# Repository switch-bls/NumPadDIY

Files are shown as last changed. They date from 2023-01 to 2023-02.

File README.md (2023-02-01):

# Projet NumPadDIY
Ce projet m'a conduit à réaliser un pavé numérique filaire pour mon bureau.
Il s'agit d'un pavé numérique complet avec la touche verr/num fonctionnelle et l'anti-ghosting.

Tenter la réalisation de ce projet vous demandera des compétences de base en soudure, impression 3D et programmation C. Bien sûr, assurez-vous également d'avoir une imprimante 3D et un poste à souder.

Fonctionnalité:
- Touche Pavé numérique
- Anti-ghosting
- port Micro USB

Matériel:
- 1 Arduino Pro Micro 
- 17 switch de clavier
- 17 diode
- Les touches correspondants au pavé numérique d'un clavier
- 6 vis M1
- Du câble
- Du filament 3D

## Étape 1 - impression 3D

La première chose à faire est d'imprimer la coque en 3D.
Elle ne comporte que 2 parties plutôt faciles à imprimé, j'ai utilisé du PLA pour ma part
Mon paramétrage d'imprimante devait être une d'épaisseur de 0.2 mm sans support.
L'imprimante depuis laquelle j'ai fait la coque est une anet a8.

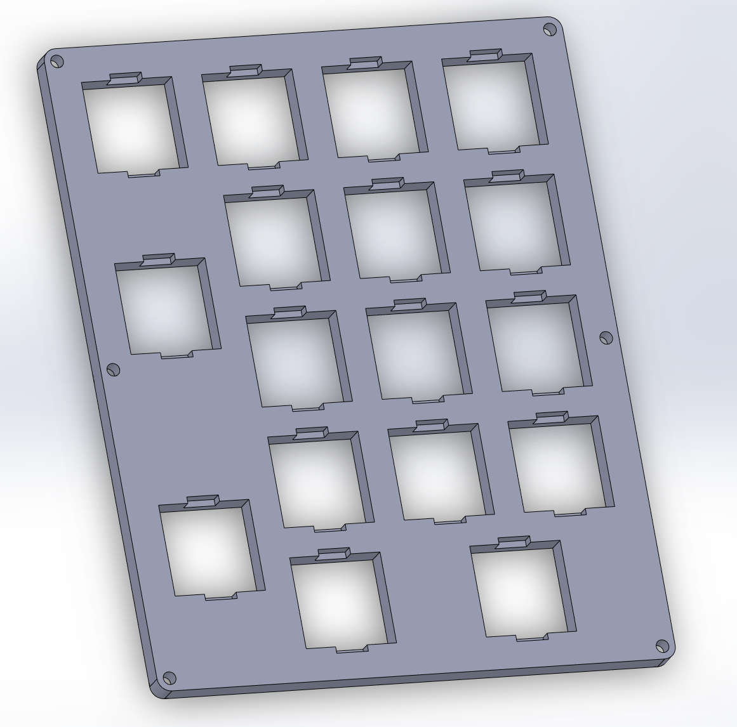
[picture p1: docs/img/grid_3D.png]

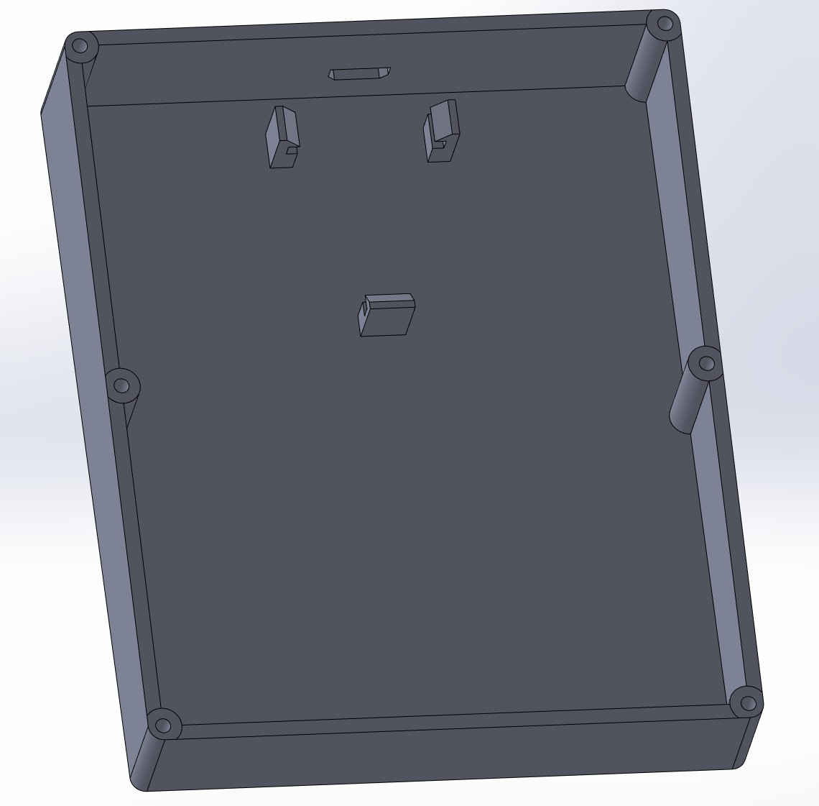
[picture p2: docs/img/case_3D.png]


Les fichier STL: https://github.com/switch-bls/NumPadDIY/tree/main/STL-3d-model

Les fichiers SolidWorks:  https://github.com/switch-bls/NumPadDIY/tree/main/SW-3d-model

## Étape 2 - Placer les switch

Placez simplement tout les switch dans le même sens sur la grille.

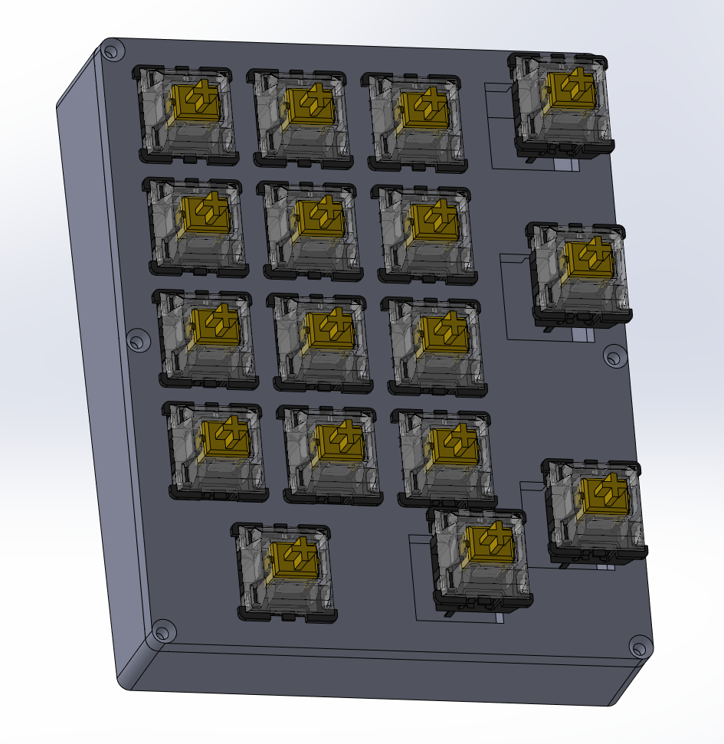
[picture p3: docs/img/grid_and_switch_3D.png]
grid_3D


Vous avez désormais une grille de bouton relier à rien. Maintenant on passe aux choses plus sérieuses.

## Étape 3 - Souder

C'est là que ça se complique, armez vous de patience pour l'étape la plus fastidieuse de ce projet (la soudure).

Tout d'abord il faut placer une diode sur chaque switche, toujours sur le même pin pour la gestion de l'anti-ghosting.

Nous allons vouloir relier les switch de notre clavier en une matrice. C'est-à-dire en ligne et en colonne, de sorte à en minimiser le nombre. Ce n'est pas grave si les lignes et les colonnes ne sont pas de la même taille.

Ce site explique en détaille l'intérêt de ce travaille:
- https://pcbheaven.com/wikipages/How_Key_Matrices_Works/

Voici mon résultat:

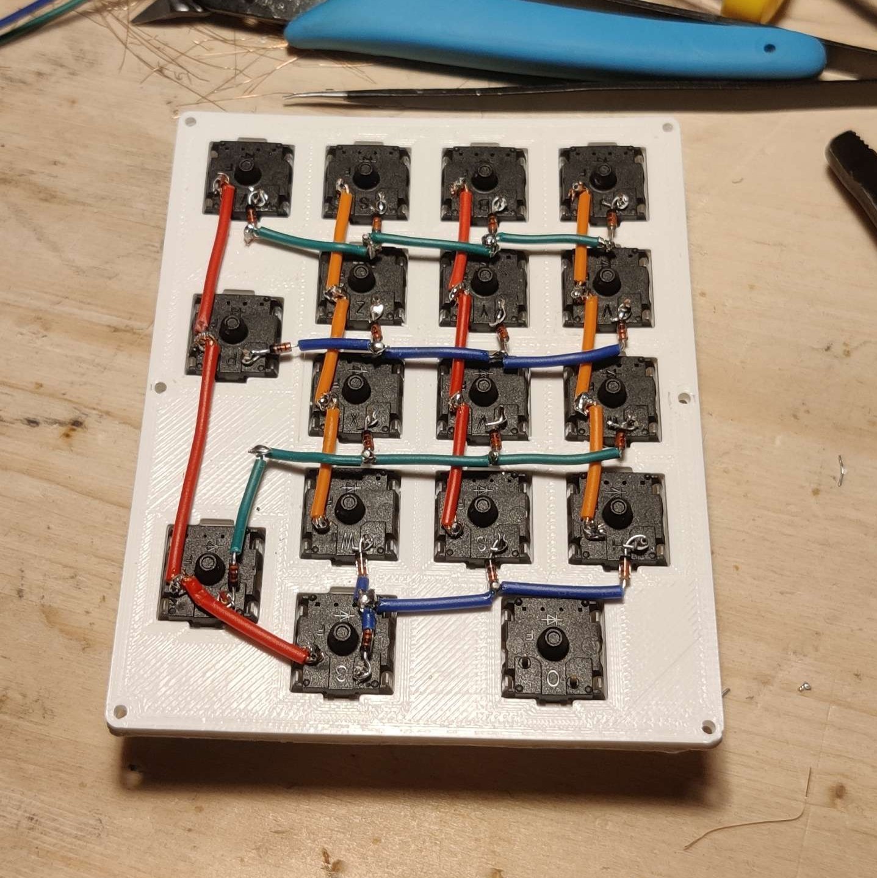
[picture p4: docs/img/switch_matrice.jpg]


Une matrice de 4*4+1.

Pour finir reliez chaque ligne et chaque colonne une fois à un pin digital de votre carte Arduino Pro Micro de sorte à laisser suffisamment de mou pour pouvoir tout positionner dans la boite.

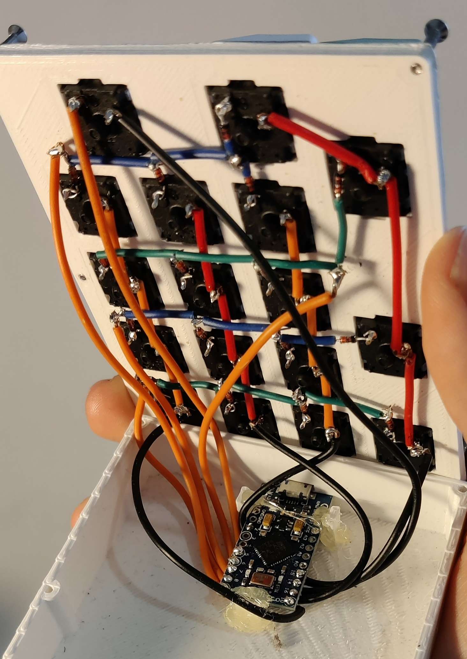
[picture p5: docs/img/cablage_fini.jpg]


Et voilà c'est fini pour la soudure!

## Étape 4 - Progrogrammer

Le code est le fichier ```code_keyboard.ino``` du projet.
Ce code n'est pas de moi, ***MAIS*** j'ai oublié la source dont il provient donc dsl pour l'auteur.

Si votre câblage est différent du mien, il va falloir adapter votre programme en conséquence.
Pas de panique, il s'agit de redéfinir quelque variable.

### Nombre de ligne et colonne
Placer le nombre de vos lignes et colonnes ici.
Ma matrice comportait 4x4+1 ce qui fait 5x5 pour ma part.

La variable *LAYERS* sert à définir différentes configuration de touches pour un même clavier mais elle n'est pas utile pour ce projet.

```C++
//Matrix Setup
const int LAYERS = 3;
const int ROWS = 5;
const int COLUMNS = 5;
```

### Définition des pins

Changez les numéros des pins pour ceux que vous avez connectés à votre micro controller. L'ordre n'est pas important.

```C++
//Input pins,
int ColPins[COLUMNS] = {8,9,7,6,5};
int RowPins[ROWS] = {14,2,16,15,10};
```

### Assigner les touches

Enfin il est temps d'assigner les touches de votre clavier à des actions dans le code (écrire des caractères). 

Tout d'abord il vous faudra initialiser un tableau de la taille de votre matrice.
Puis il faudra verifier ce que l'on appelle le scan-code de chaque touche en essayant de voir à quelle touche correspond quelle valeur.

Ici, le scan code est écrit en binaire, si vous le pouvez, faite le en hexadécimale se sera plus simple.

Pour connaître le scan-code des touche:
- https://forum.arduino.cc/t/numpad-keys/257542/4
- http://www.quadibloc.com/comp/scan.htm

```C++
const unsigned int Keymap[LAYERS][ROWS][COLUMNS] = 
{
  {//0 Raised layer
    {
      222,//  -
      235, // .
      223, // +
      224, // Enter
      NO_ACTION //  
    },
    {
      221, // *
      227, // 3
      233, // 9
      230, // 6
      NO_ACTION  // 
    },
    {
      220, // //
      226, // 2
      232, // 8
      229, // 5
      NO_ACTION  //
    },
    {
      NO_ACTION, //
      NO_ACTION, // 
      NO_ACTION, //
      NO_ACTION, // 
      234, // 0
    },
    {
      219,  // META
      225,  // 1
      231, // 7
      228,  // 4
      NO_ACTION,  
    }
   }
 };
```

## Étape 4 - Assemblage finale

Une fois cette opération achevéé, il ne reste qu'à coller la carte à l'emplacement prévu. J'ai utilisé du pistolet à colle pour ça.

Vissez le tout avec des vis M1 et placez vos keyCap sur les switches correspondant si ce n'est pas déjà fait et voilà!

Votre Pavé Numérique est opérationnel.

## Sources utiles

- https://pcbheaven.com/wikipages/How_Key_Matrices_Works/
- http://www.philipstorr.id.au/pcbook/book3/scancode.htm
- http://www.quadibloc.com/comp/scan.htm
- https://forum.arduino.cc/t/numpad-keys/257542/4

<style>
img{max-width:500px;}
img{min-width:300px;}
img{width:49%;}
</style>

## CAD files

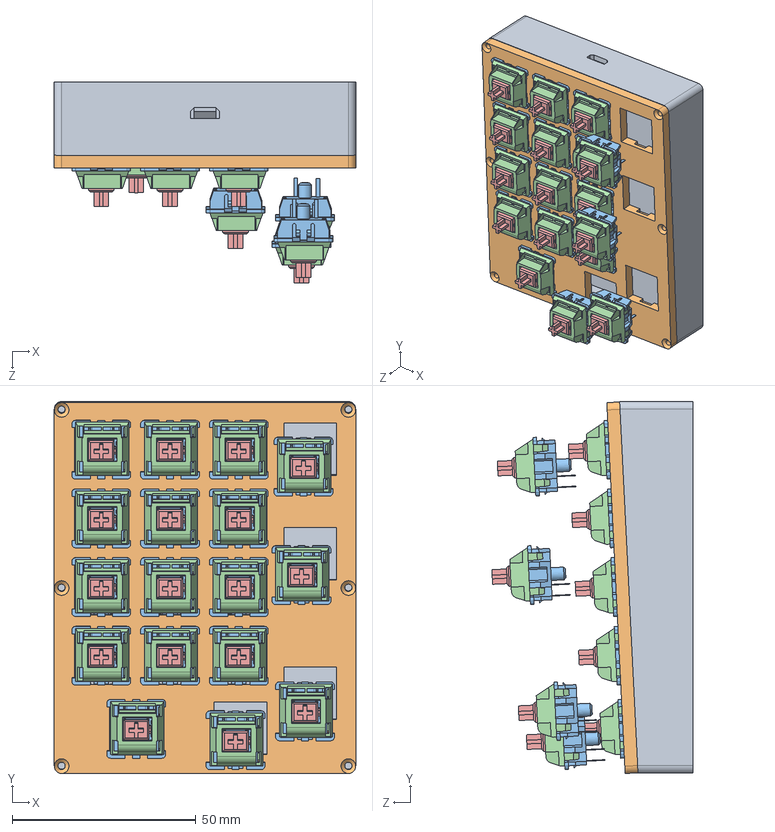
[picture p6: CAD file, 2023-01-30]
SW-3d-model/Assemblage2.SLDASM
82.0 x 101.2 x 54.7 mm
Case1.0
SwitchHolder3.2
CherrySwitchBottom1 x 17
CherrySwitchTop1 x 17
Piston1 x 17

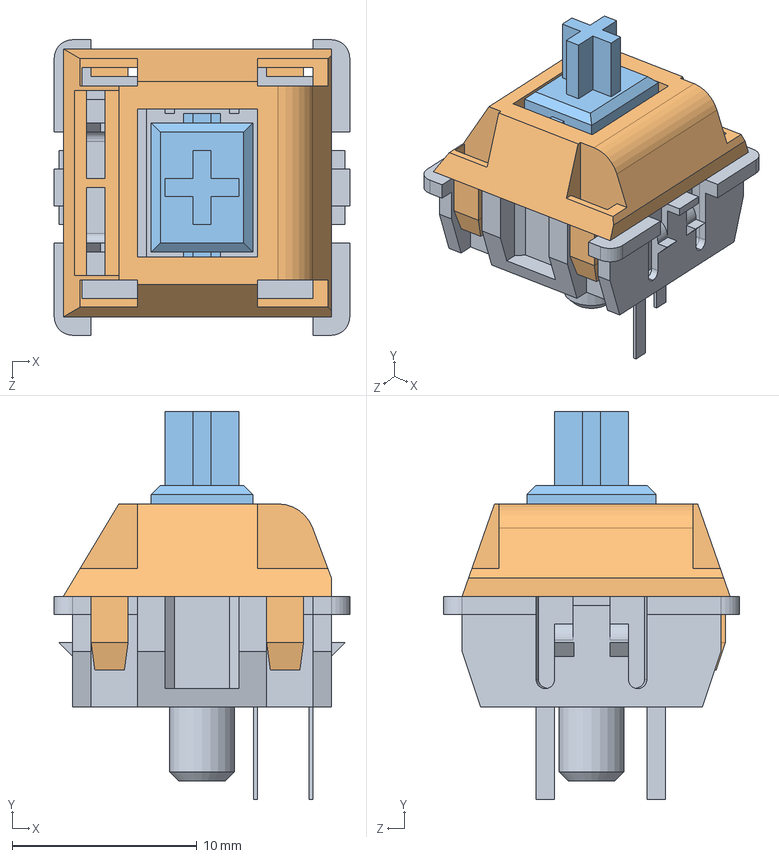
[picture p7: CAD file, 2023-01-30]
SW-3d-model/Assemblage1.SLDASM
16.0 x 21.0 x 16.0 mm
CherrySwitchBottom1
CherrySwitchTop1
Piston1

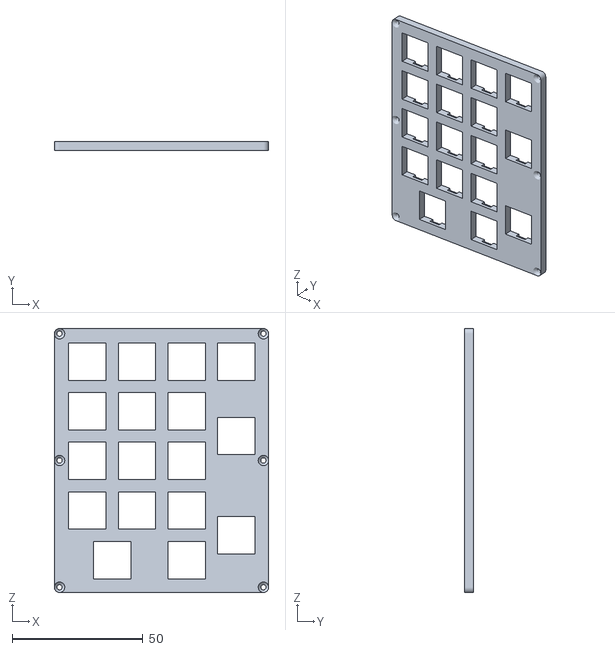
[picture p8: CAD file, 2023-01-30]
STL-3d-model/SwitchHolder3.2.STL
82.0 x 3.50 x 101.0

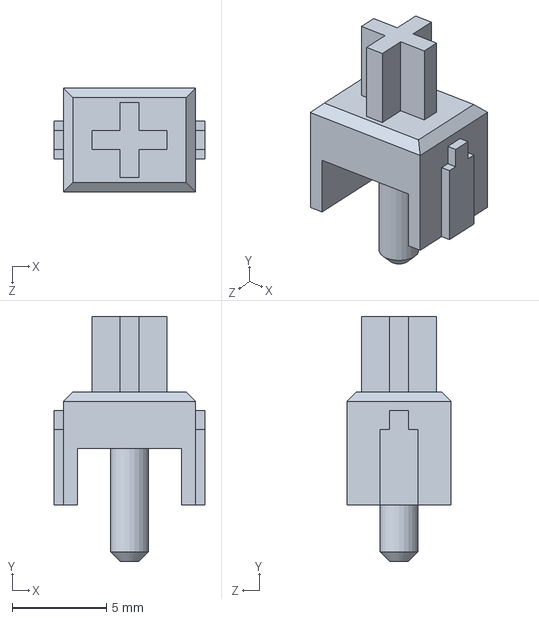
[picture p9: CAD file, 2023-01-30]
SW-3d-model/Piston1.SLDPRT
8.00 x 13.0 x 5.50 mm

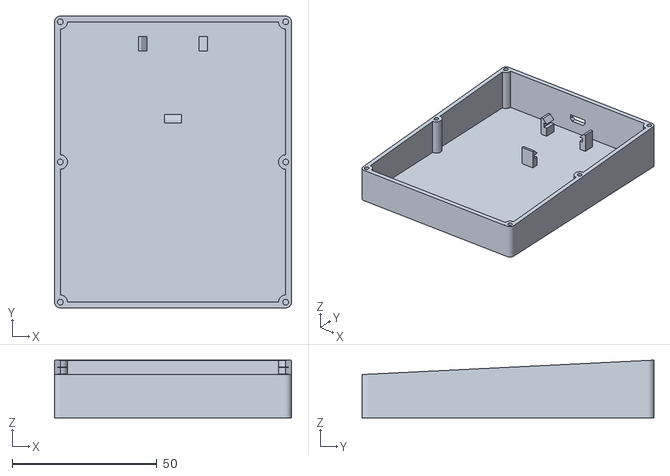
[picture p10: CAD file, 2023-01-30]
STL-3d-model/Case1.0.STL
82.0 x 101.0 x 20.0

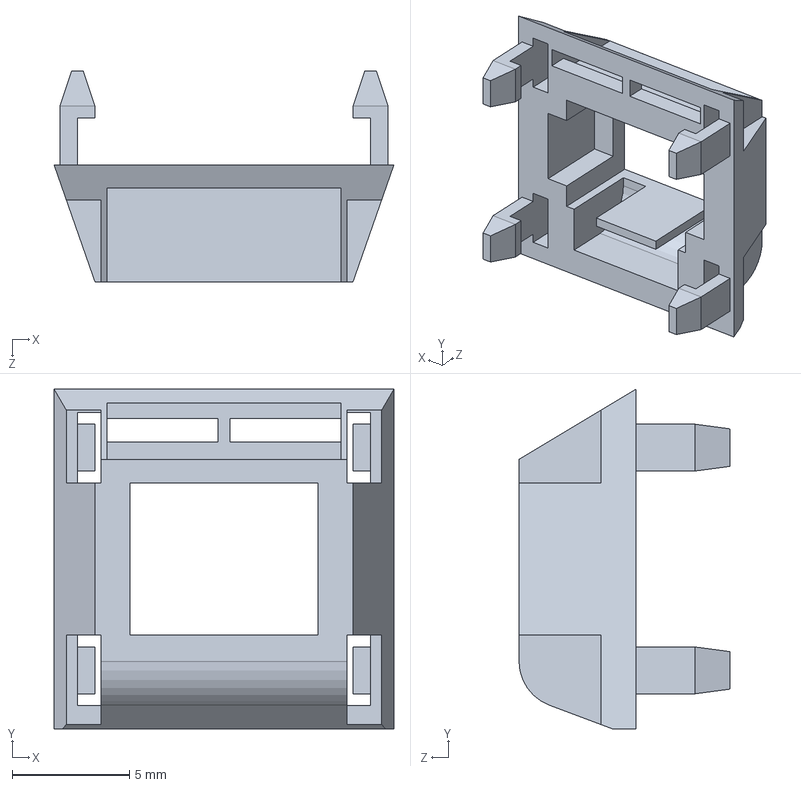
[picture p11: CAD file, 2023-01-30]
SW-3d-model/CherrySwitchTop1.SLDPRT
14.5 x 14.5 x 9.00 mm

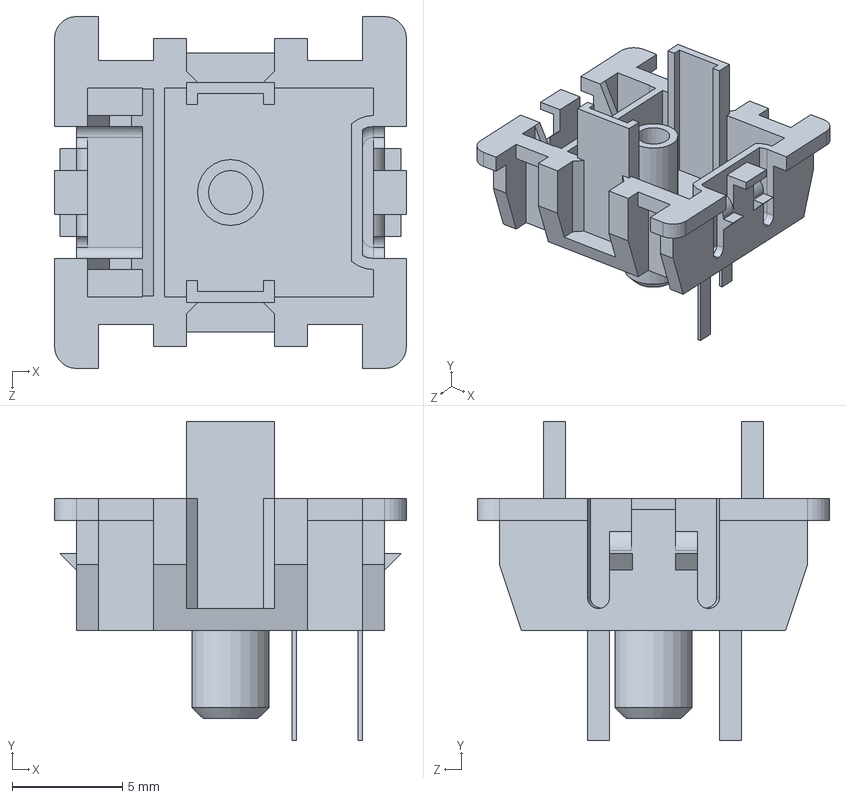
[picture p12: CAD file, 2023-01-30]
SW-3d-model/CherrySwitchBottom1.SLDPRT
16.0 x 14.5 x 16.0 mm

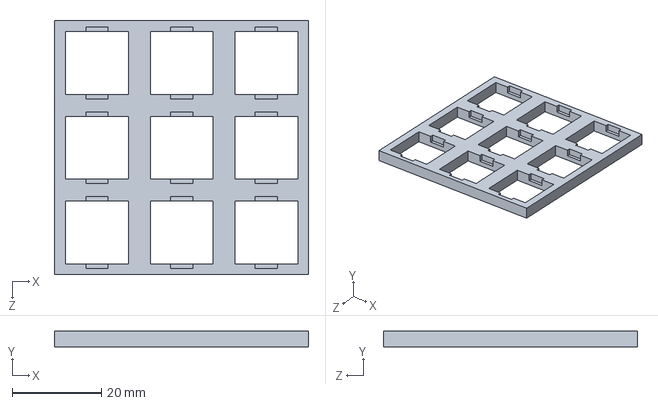
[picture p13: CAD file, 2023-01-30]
SW-3d-model/SwitchHolder2.1.SLDPRT
57.0 x 3.50 x 57.0 mm

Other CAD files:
SW-3d-model/Case1.0.SLDPRT
SW-3d-model/SwitchHolder3.2.SLDPRT

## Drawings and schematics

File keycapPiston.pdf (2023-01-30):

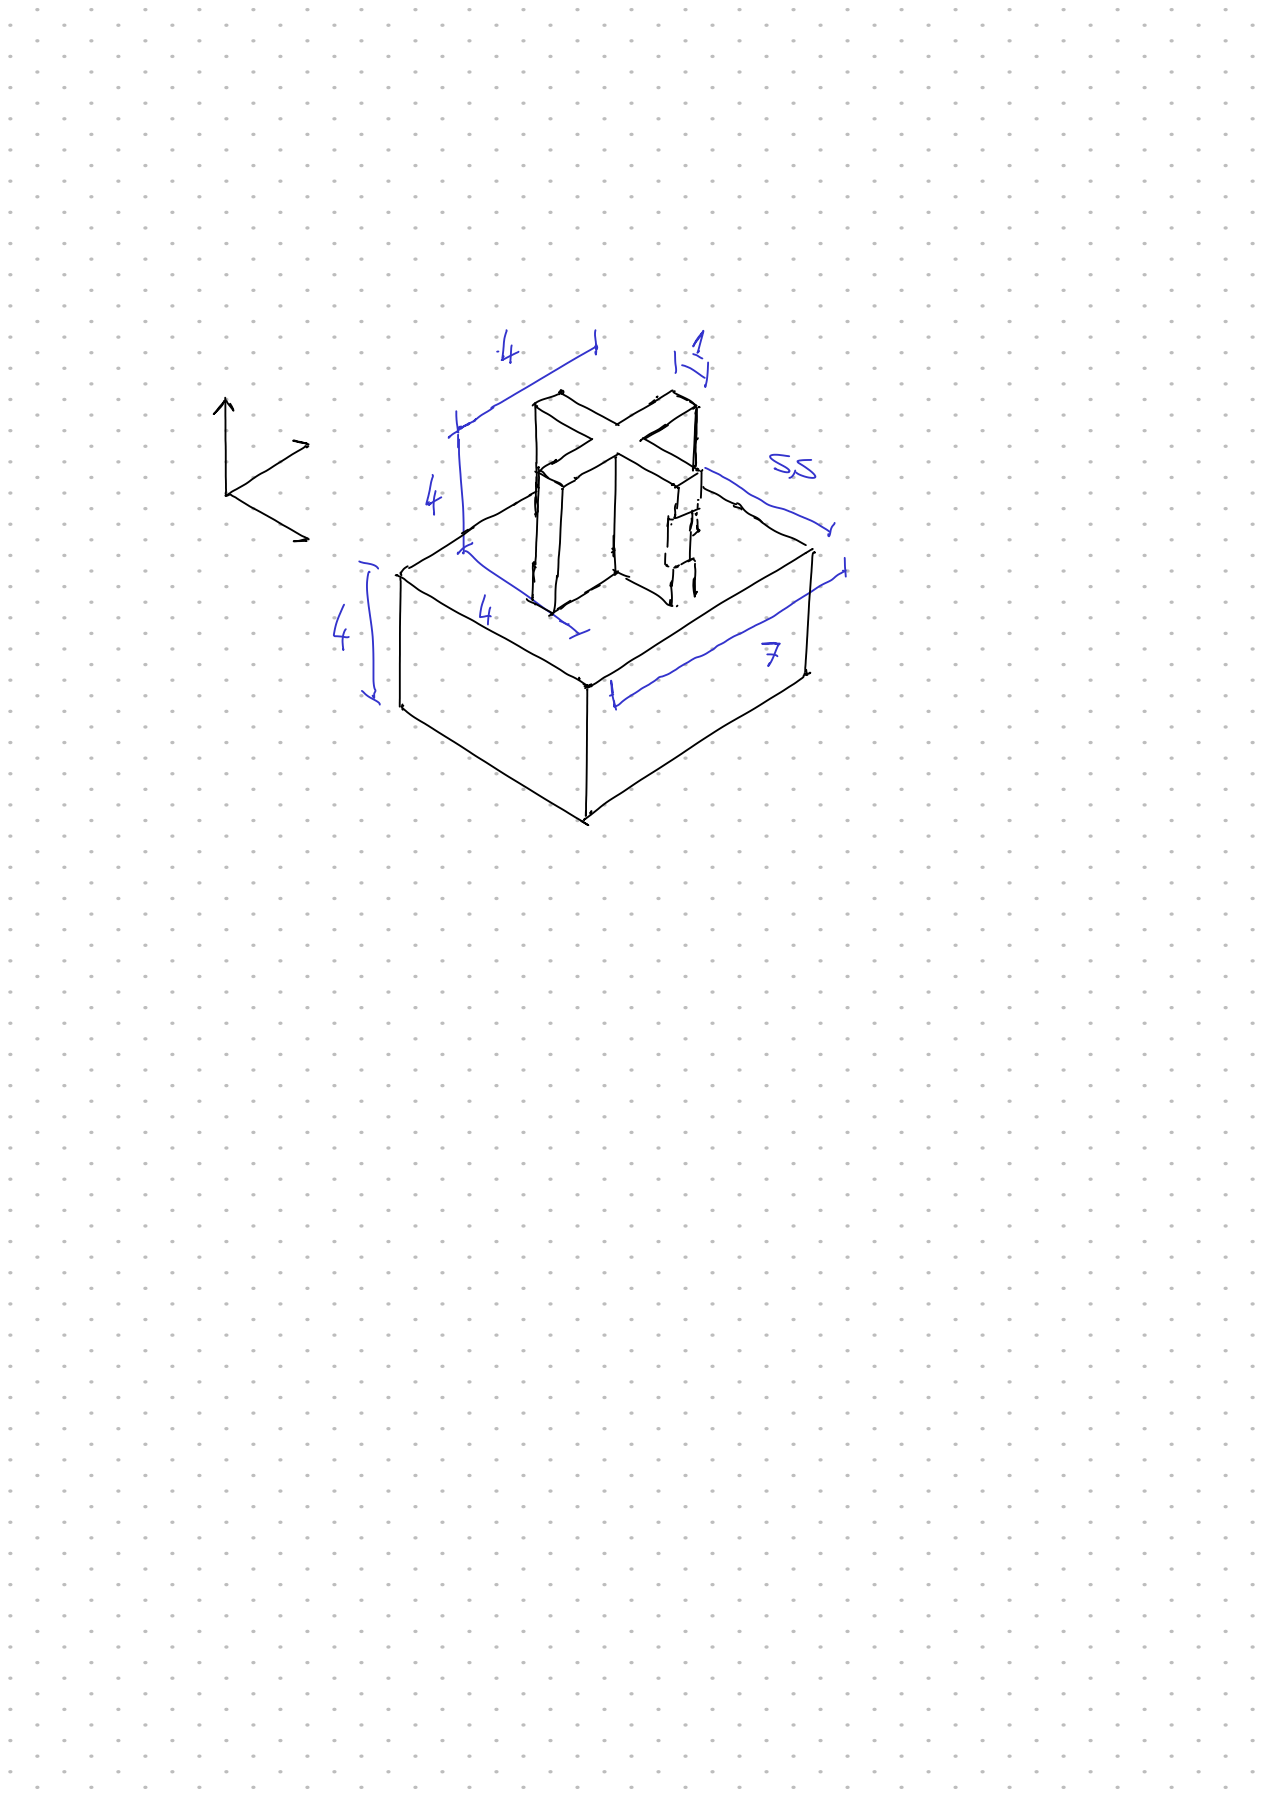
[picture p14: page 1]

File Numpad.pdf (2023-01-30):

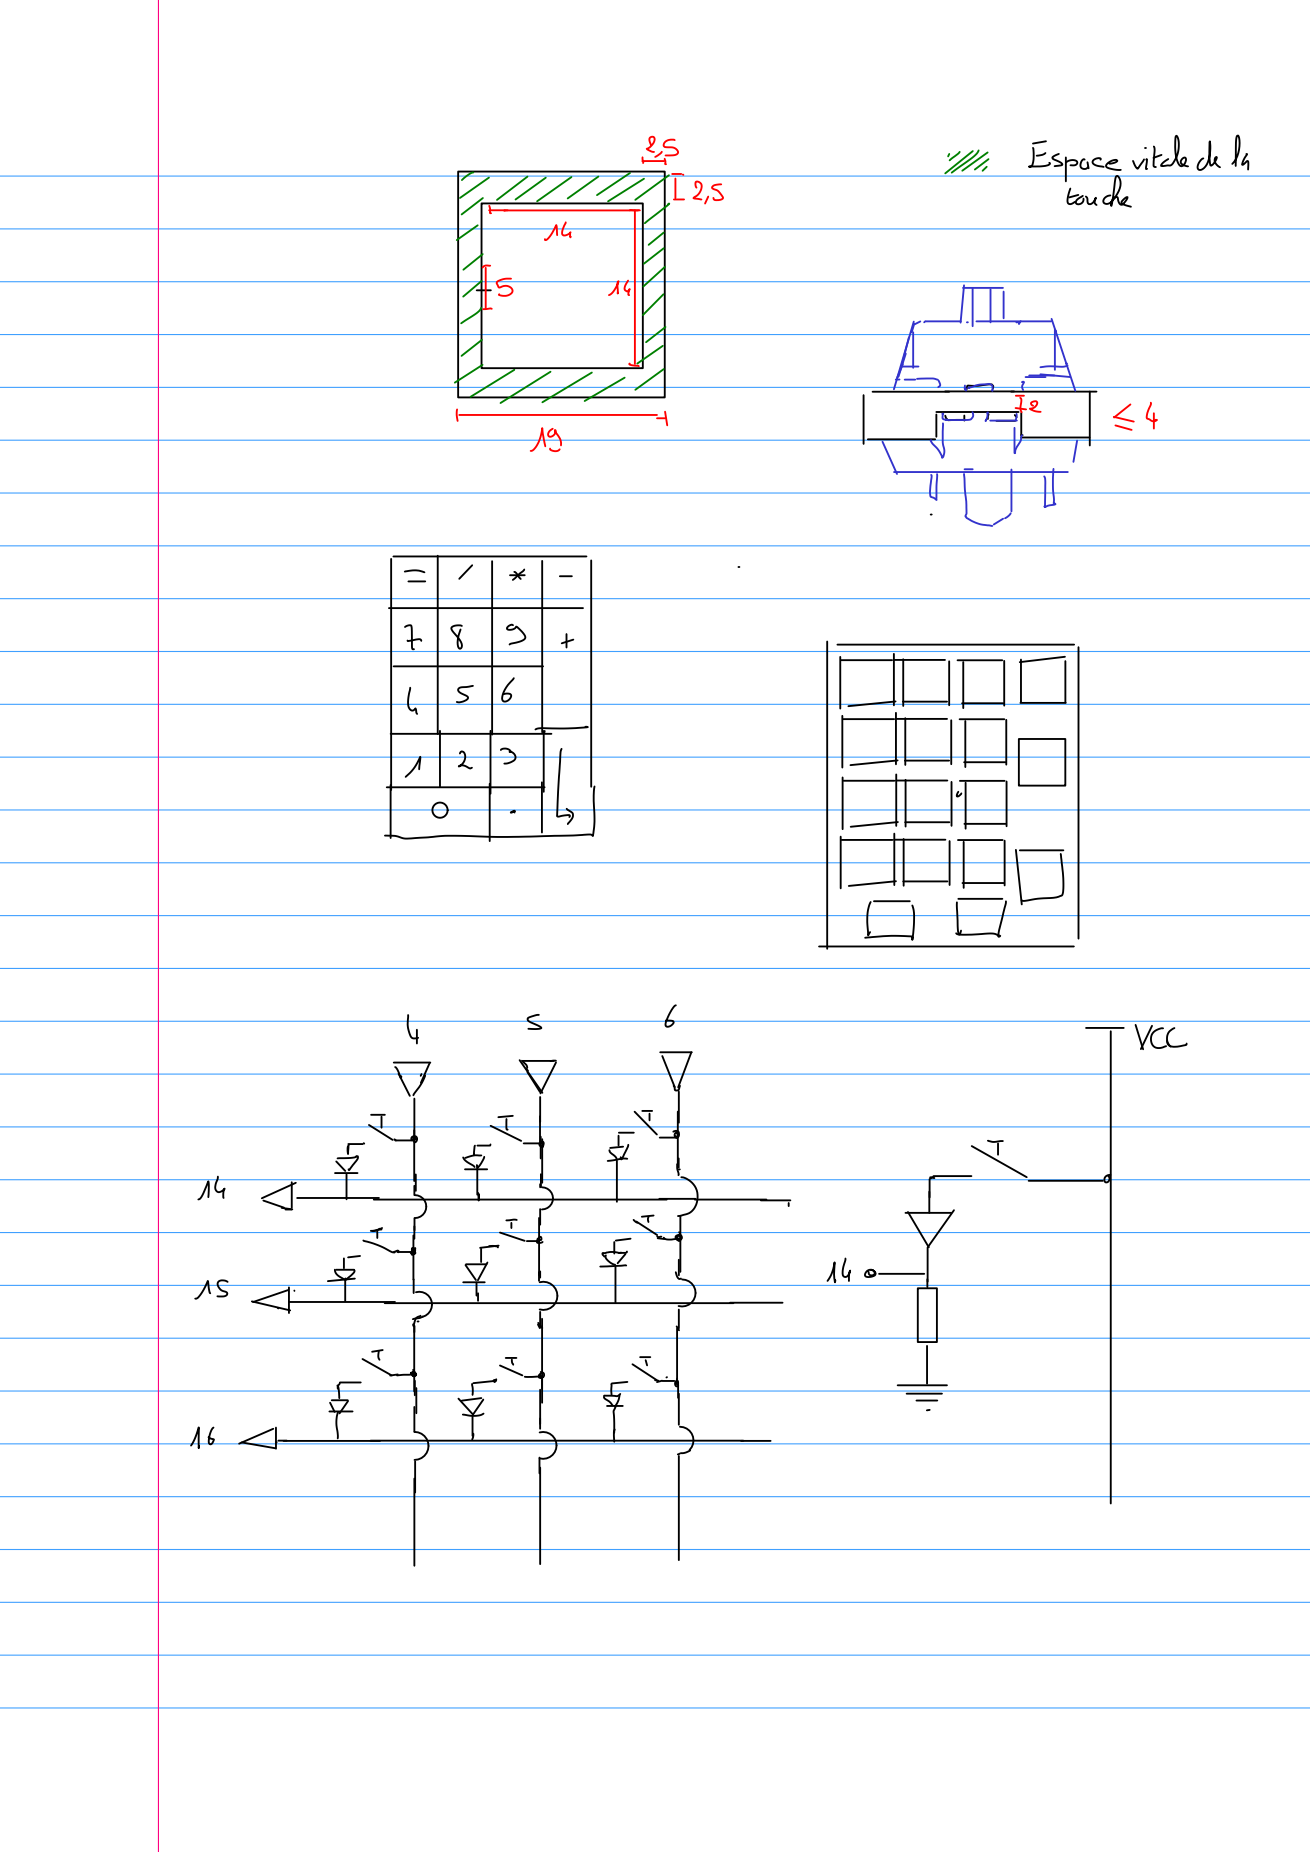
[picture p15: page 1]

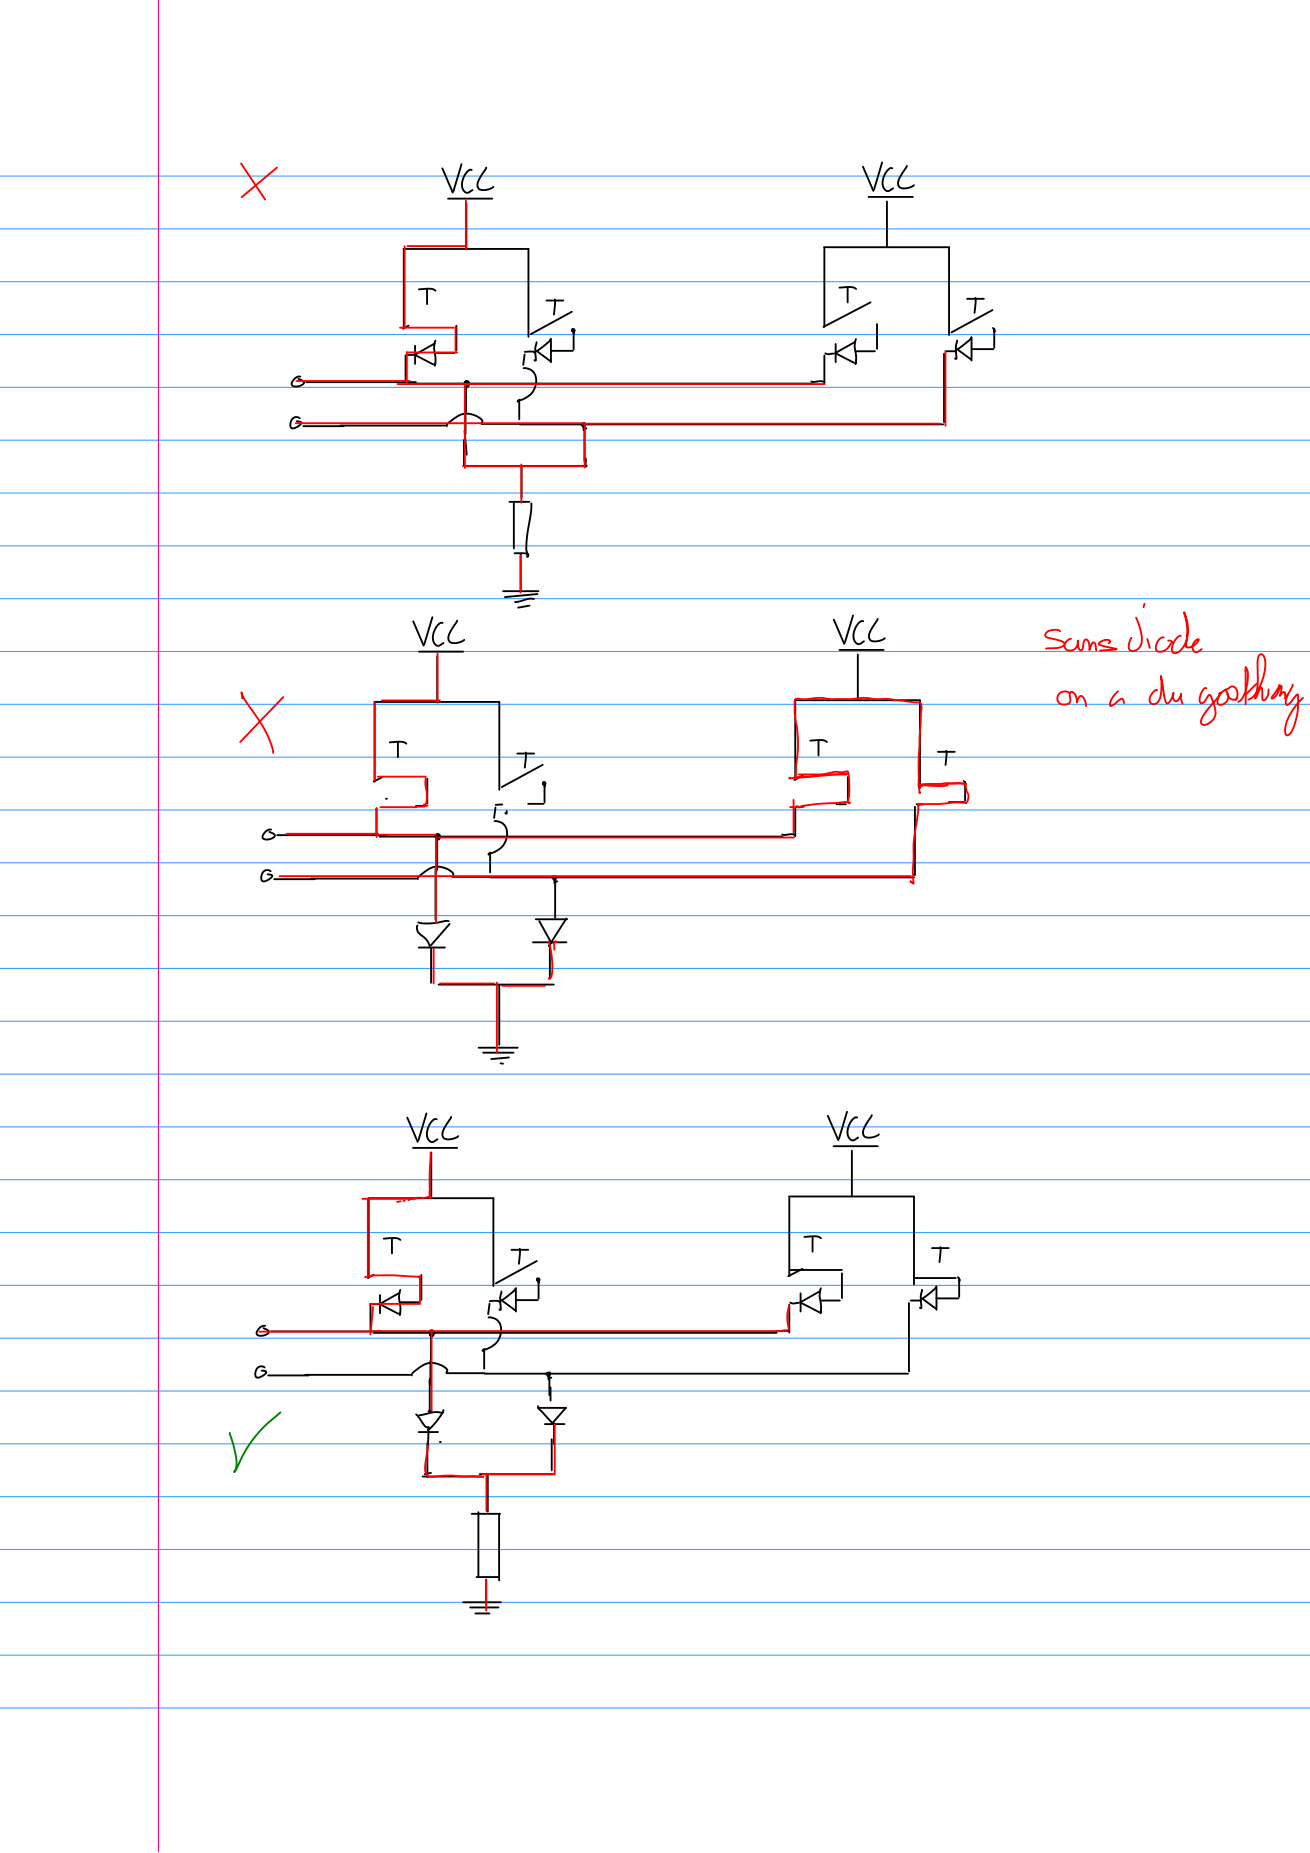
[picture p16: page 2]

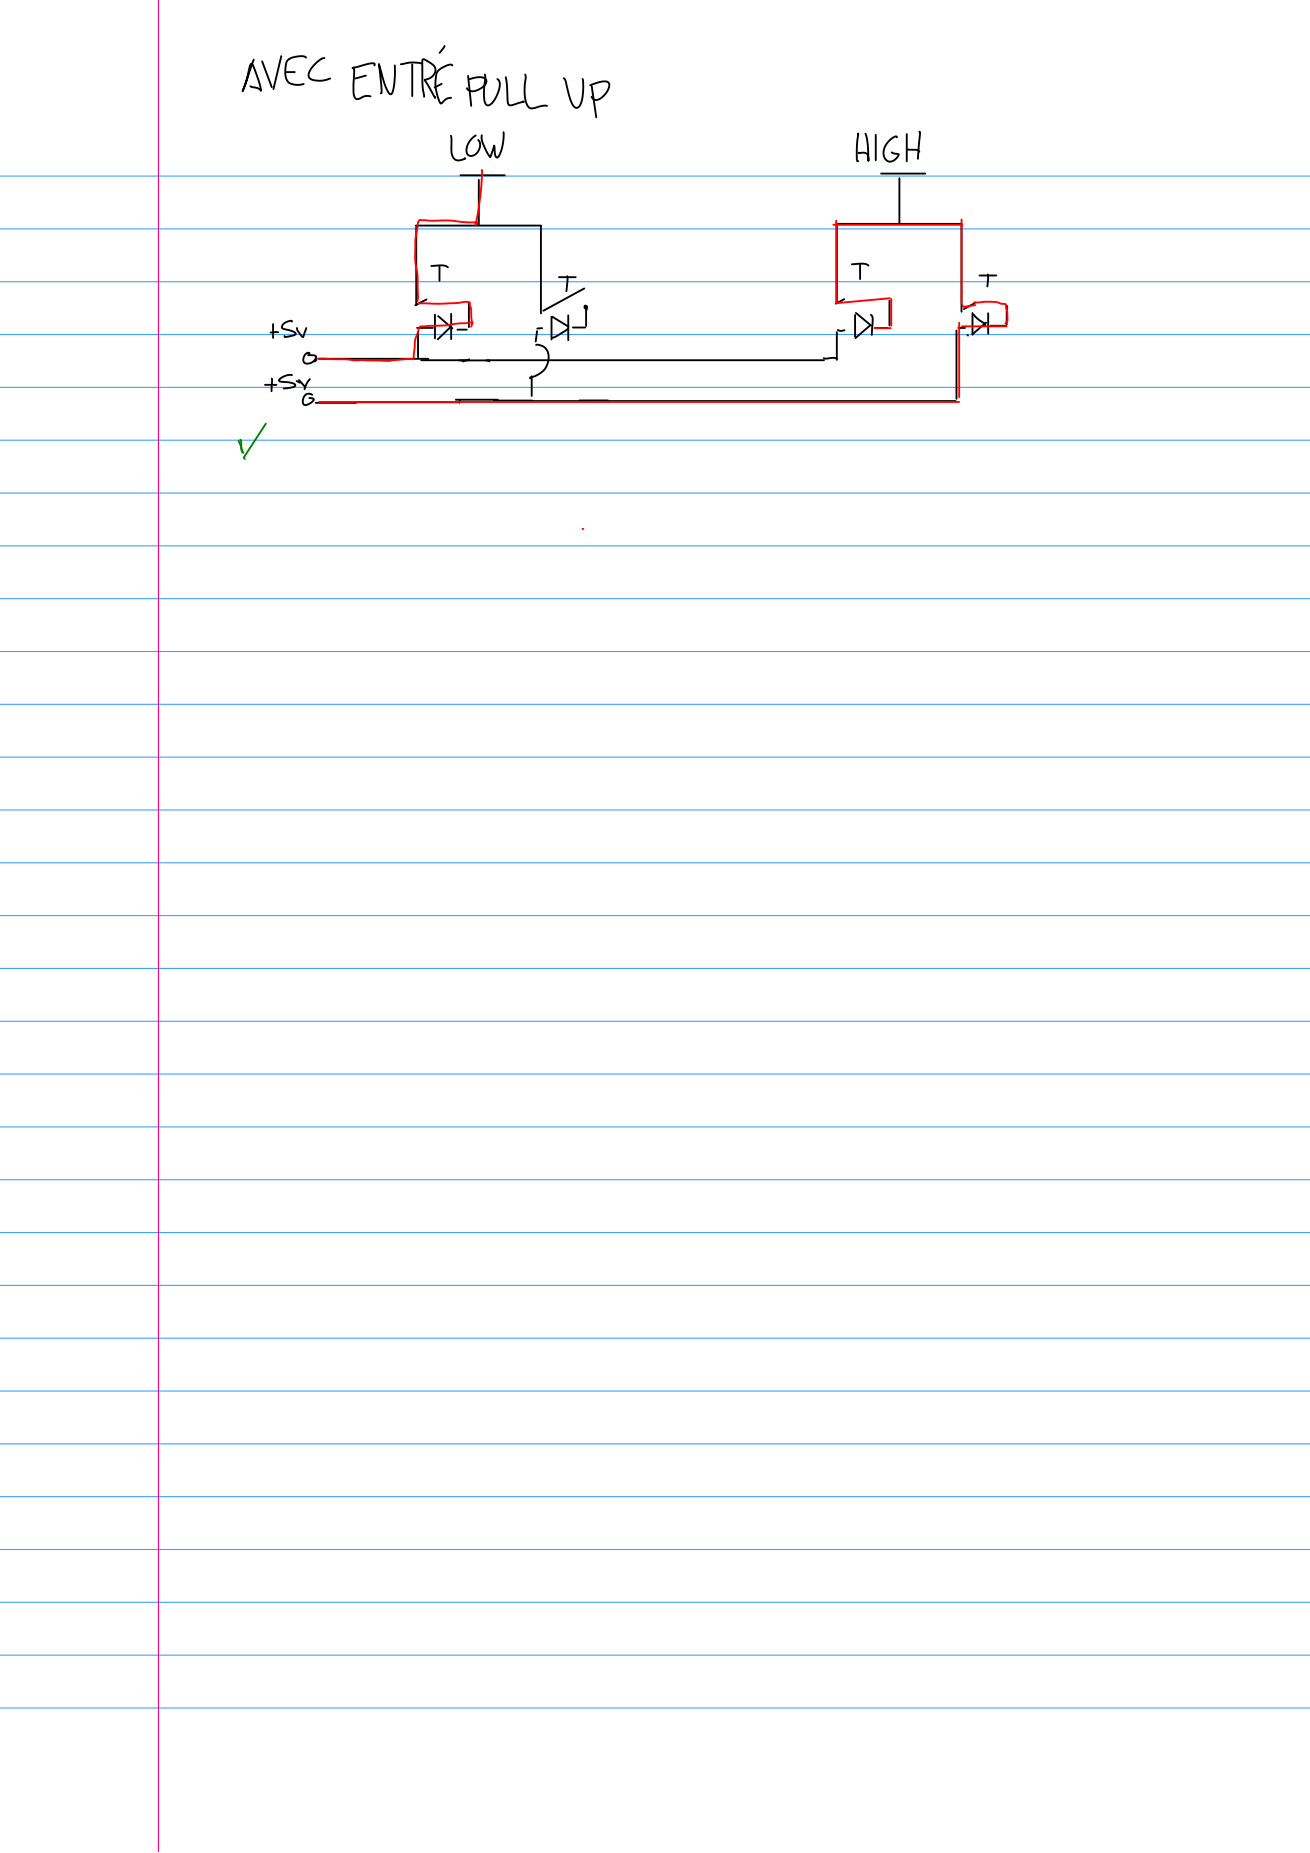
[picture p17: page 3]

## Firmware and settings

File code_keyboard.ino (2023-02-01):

#include <Keyboard.h>


////Config variables
//Matrix Setup
const int LAYERS = 3;
const int ROWS = 5;
const int COLUMNS = 5;

//Loop Delay
int delayLoopPin = 3;

//Input pins,
int ColPins[COLUMNS] = {8,9,7,6,5};
int RowPins[ROWS] = {14,2,16,15,10};

//Output debug info to serial monitor
const bool EnableDebug = true;

////System Variables

//Default Buttons
const int NO_ACTION = 0;
const int LAYER_RAISE = 1;
const int LAYER_LOWER = 2;

//Keymap
bool switchStates[ROWS][COLUMNS];
int currentLayer = 0; //0 raised; 1 default; 2 lowered; 

const unsigned int Keymap[LAYERS][ROWS][COLUMNS] = 
{
  {//0 Raised layer
    {
      222,//  -
      235, // .
      223, // +
      224, // Enter
      NO_ACTION //  
    },
    {
      221, // *
      227, // 3
      233, // 9
      230, // 6
      NO_ACTION  // 
    },
    {
      220, // //
      226, // 2
      232, // 8
      229, // 5
      NO_ACTION  //
    },
    {
      NO_ACTION, //
      NO_ACTION, // 
      NO_ACTION, //
      NO_ACTION, // 
      234, // 0
    },
    {
      219,  // META
      225,  // 1
      231, // 7
      228,  // 4
      NO_ACTION,  
    }
   }
 };


void setup()
{
  setupPins();
  Serial.begin(9600); 
  pinMode(11, OUTPUT);
}

void delayByPin() {
  //If delayPin becomes low (connected to ground) then delay loop
  //implemented to stop the chip from becoming stuck in a key spamming loop
  //Note: Can be removed if in need of the extra pin.
  while (digitalRead(delayLoopPin) == LOW) 
  {
    delay(8000);
  }
}

void loop()
{
  delayByPin();
  switchMatrixLoop();
  delay(10);
}

void setupPins() {
  pinMode(delayLoopPin, INPUT_PULLUP);

  //Setup col pins
  for(int i=0; i<COLUMNS; i++){
    pinMode(ColPins[i], INPUT_PULLUP);
  }

  //Setup row pins
  for(int i=0; i<ROWS; i++){
    pinMode(RowPins[i], OUTPUT);
  }
}

void switchMatrixLoop() {
  //loop through columns, loop through rows and read outputs
  for(int row = 0; row < ROWS; row++) 
  {
    digitalWrite(RowPins[row], LOW); //Power Low on column
    for(int column = 0; column < COLUMNS; column++)
    {
      //Pass inverted pin state of ColPin as row state because of INPUT_PULLUP
      //If the switch is pressed, this column should be pulled LOW by the column pin.
      //By inverting this a pressed key is 1 and a released key is 0.
      keyChangeCheck(!digitalRead(ColPins[column]), row, column);       
    }
    digitalWrite(RowPins[row], HIGH); //Power back to High on Column
  }
}
          

void releaseAllSwitchStates() //Clear switchStates array
{
  for(int y = 0; y < ROWS; y++){
    for(int z = 0; z < COLUMNS; z++){
      switchStates[y][z] = false;
    }
  }
}

void keyChangeCheck(bool currentState, int row, int column) 
{  
  bool previousState = switchStates[row][column];
  if(currentState == previousState)   //Key is the same
  {
    //No change;
  }
  else if (currentState == HIGH)      //Key is pressed
  {
    switchStates[row][column] = true;
    keyPressHandler(Keymap[currentLayer][row][column]);
    
    DebugPrintKeyState();
  }
  else                                //Key is released
  {
    //Serial.println(String(Keymap[currentLayer][row][column]) + String(" Key released, Layer: ") + currentLayer + String(" Row: ") + row + String(" Column: ") + column);
    switchStates[row][column] = false;
    keyReleaseHandler(Keymap[currentLayer][row][column]);

    DebugPrintKeyState();
  }
}
void keyPressHandler(int key) //Key Press
{
  if(key == LAYER_RAISE){
    Keyboard.releaseAll();
    releaseAllSwitchStates();
    currentLayer = 0;
  }
  else if(key == LAYER_LOWER){
    Keyboard.releaseAll();
    releaseAllSwitchStates();
    currentLayer = 2;
  }
  else if(key == NO_ACTION){
    // Do nothing
  }
  else {
    digitalWrite(11, HIGH); 
    Keyboard.press(key);
  }
}

void keyReleaseHandler(int key) //Key Release
{
  if(key == LAYER_RAISE){
    Keyboard.releaseAll();
    releaseAllSwitchStates();
    currentLayer = 1;
  }
  else if(key == LAYER_LOWER){
    Keyboard.releaseAll();
    releaseAllSwitchStates();
    currentLayer = 1;
  }
  else if(key == NO_ACTION){
    // Do nothing
  }
  else {
    Keyboard.release(key);
    digitalWrite(11, LOW);
  }
}


void DebugPrintKeyState()//Debugging
{
  if(EnableDebug)
  {
  Serial.println("Matrix State:");
  for(int y = 0; y < ROWS; y++){
    for(int z = 0; z < COLUMNS; z++){
      Serial.print(switchStates[y][z]);  
    }
    Serial.println("");
   }   
   Serial.println("");
  }
}
